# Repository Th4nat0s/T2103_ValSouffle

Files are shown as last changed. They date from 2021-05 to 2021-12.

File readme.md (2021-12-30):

Blow Gun controller for CNC
===========================

Print it on your CNC !

Push code to arduino
--------------------------------

### Arduino
Usb connection 
arduino framework 

Tips
----
`./serial` launch serial console through buspirate  
`pio run -t idedata` update libs, perpare env  
`pio run -t fuses` set the fuses  
`pio run -t upload -e release|debug` upload  a specific release version without serial debug  
`pio platform update --dry-run` check for updates

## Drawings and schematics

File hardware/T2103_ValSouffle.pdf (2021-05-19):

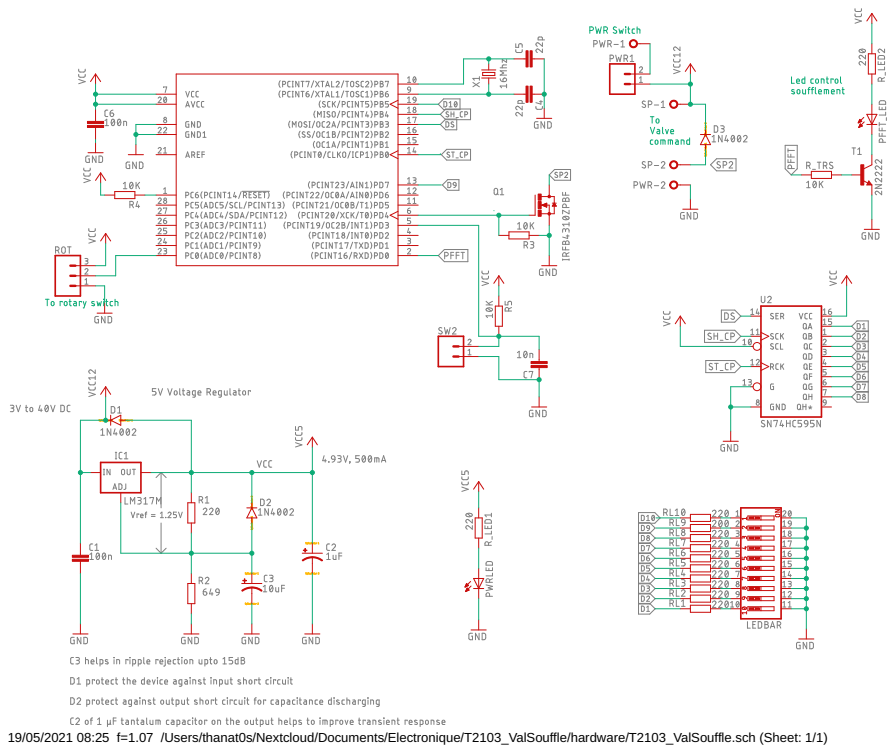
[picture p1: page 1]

19/05/2021 08:25 f=1.07 /Users/thanat0s/Nextcloud/Documents/Electronique/T2103_ValSouffle/hardware/T2103_ValSouffle.sch (Sheet: 1/1)

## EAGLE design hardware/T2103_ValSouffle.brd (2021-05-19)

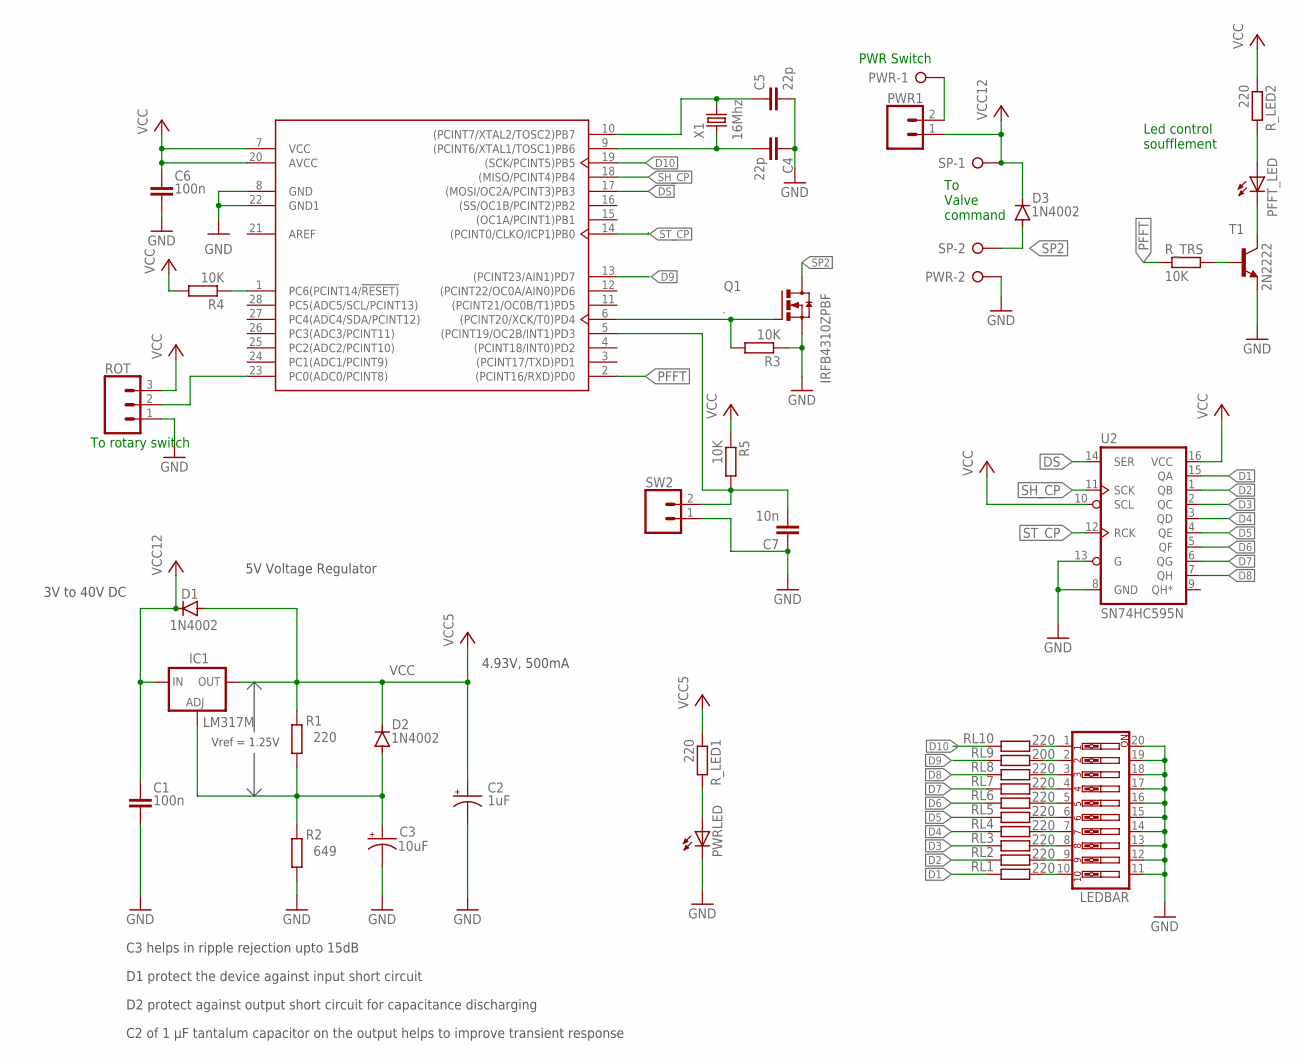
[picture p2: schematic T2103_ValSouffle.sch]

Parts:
C1, C6: 100n; C050-030X075
C2: 1uF; E1,8-4
C3: 10uF; E1,8-4
C4, C5: 22p; C025-025X050
C7: 10n; C025-025X050
D1, D2, D3: 1N4002; DO41-10
IC1: LM317MB; TO220L1; PARTNUMBER LM317M
LEDBAR: SW_DIP-10; EDG-10
PFFT_LED: LED5MM
PWR: W237-02P; W237-132
PWR1: CONN_02; 1X02
PWRLED: LED5MM
Q1: IRFB4310ZPBF; TO-220
R1: 220; 0207/10
R2: 649; 0207/10
R3, R4, R5: 10K; 0207/10
RL1, RL2, RL3, RL4, RL5, RL6, RL7, RL8, RL10: 220; 0207/10
RL9: 200; 0207/10
ROT: CONN_03; 1X03
R_LED1, R_LED2: 220; 0207/10
R_TRS: 10K; 0207/10
SP: W237-02P; W237-132
SW2: CONN_02; 1X02
T1: 2N2222; TO92-EBC-OVAL
U1: ATMEGA328P-PU; DIP-28
U2: SN74HC595N; DIP16
X1: 16Mhz; XTAL_HC49

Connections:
D1: RL1.2, U2.15 (QA)
D2: RL2.2, U2.1 (QB)
D3: RL3.2, U2.2 (QC)
D4: RL4.2, U2.3 (QD)
D5: RL5.2, U2.4 (QE)
D6: RL6.2, U2.5 (QF)
D7: RL7.2, U2.6 (QG)
D8: RL8.2, U2.7 (QH)
D9: RL9.2, U1.13 ((PCINT23/AIN1)PD7)
D10: RL10.2, U1.19 ((SCK/PCINT5)PB5)
DS: U1.17 ((MOSI/OC2A/PCINT3)PB3), U2.14 (SER)
GND: C1.2, C2.-, C3.-, C4.1, C5.2, C6.2, C7.1, LEDBAR.11, LEDBAR.12, LEDBAR.13, LEDBAR.14, LEDBAR.15, LEDBAR.16, LEDBAR.17, LEDBAR.18, LEDBAR.19, LEDBAR.20, PWR.2, PWRLED.K (C), Q1.S, R2.1, R3.1, ROT.1, SW2.1, T1.E, U1.8 (GND), U1.22 (GND1), U2.8 (GND), U2.13 (G)
unnamed: C3.+, D2.A, IC1.1 (ADJ), R1.1, R2.2
unnamed: C4.2, U1.9 ((PCINT6/XTAL1/TOSC1)PB6), X1.1
unnamed: C5.1, U1.10 ((PCINT7/XTAL2/TOSC2)PB7), X1.2
unnamed: Q1.G, R3.2, U1.6 ((PCINT20/XCK/T0)PD4)
unnamed: R4.1, U1.1 (PC6(PCINT14/!RESET))
unnamed: LEDBAR.1, RL10.1
unnamed: LEDBAR.2, RL9.1
unnamed: LEDBAR.3, RL8.1
unnamed: LEDBAR.4, RL7.1
unnamed: LEDBAR.5, RL6.1
unnamed: LEDBAR.6, RL5.1
unnamed: LEDBAR.7, RL4.1
unnamed: LEDBAR.8, RL3.1
unnamed: LEDBAR.9, RL2.1
unnamed: LEDBAR.10, RL1.1
unnamed: ROT.2, U1.23 (PC0(ADC0/PCINT8))
unnamed: PFFT_LED.A, R_LED2.2
unnamed: PFFT_LED.K (C), T1.C
unnamed: PWRLED.A, R_LED1.2
unnamed: R_TRS.2, T1.B
unnamed: C7.2, R5.2, SW2.2, U1.5 ((PCINT19/OC2B/INT1)PD3)
PFFT: R_TRS.1, U1.2 ((PCINT16/RXD)PD0)
SH_CP: U1.18 ((MISO/PCINT4)PB4), U2.11 (SCK)
SP2: D3.A, Q1.D, SP.2
ST_CP: U1.14 ((PCINT0/CLKO/ICP1)PB0), U2.12 (RCK)
VCC: C2.+, C6.1, D1.A, D2.C, IC1.2 (OUT), R1.2, R4.2, R5.1, ROT.3, R_LED1.1, R_LED2.1, U1.7 (VCC), U1.20 (AVCC), U2.10 (SCL), U2.16 (VCC)
VCC12: C1.1, D1.C, D3.C, IC1.3 (IN), PWR1.1, SP.1
VCCSHUT: PWR.1, PWR1.2

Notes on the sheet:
5V Voltage Regulator
C3 helps in ripple rejection upto 15dB
D1 protect the device against input short circuit
D2 protect against output short circuit for capacitance discharging
C2 of 1 µF tantalum capacitor on the output helps to improve transient response
4.93V, 500mA
3V to 40V DC
Vref = 1.25V
Led control soufflement
PWR Switch
To Valve command
To rotary switch

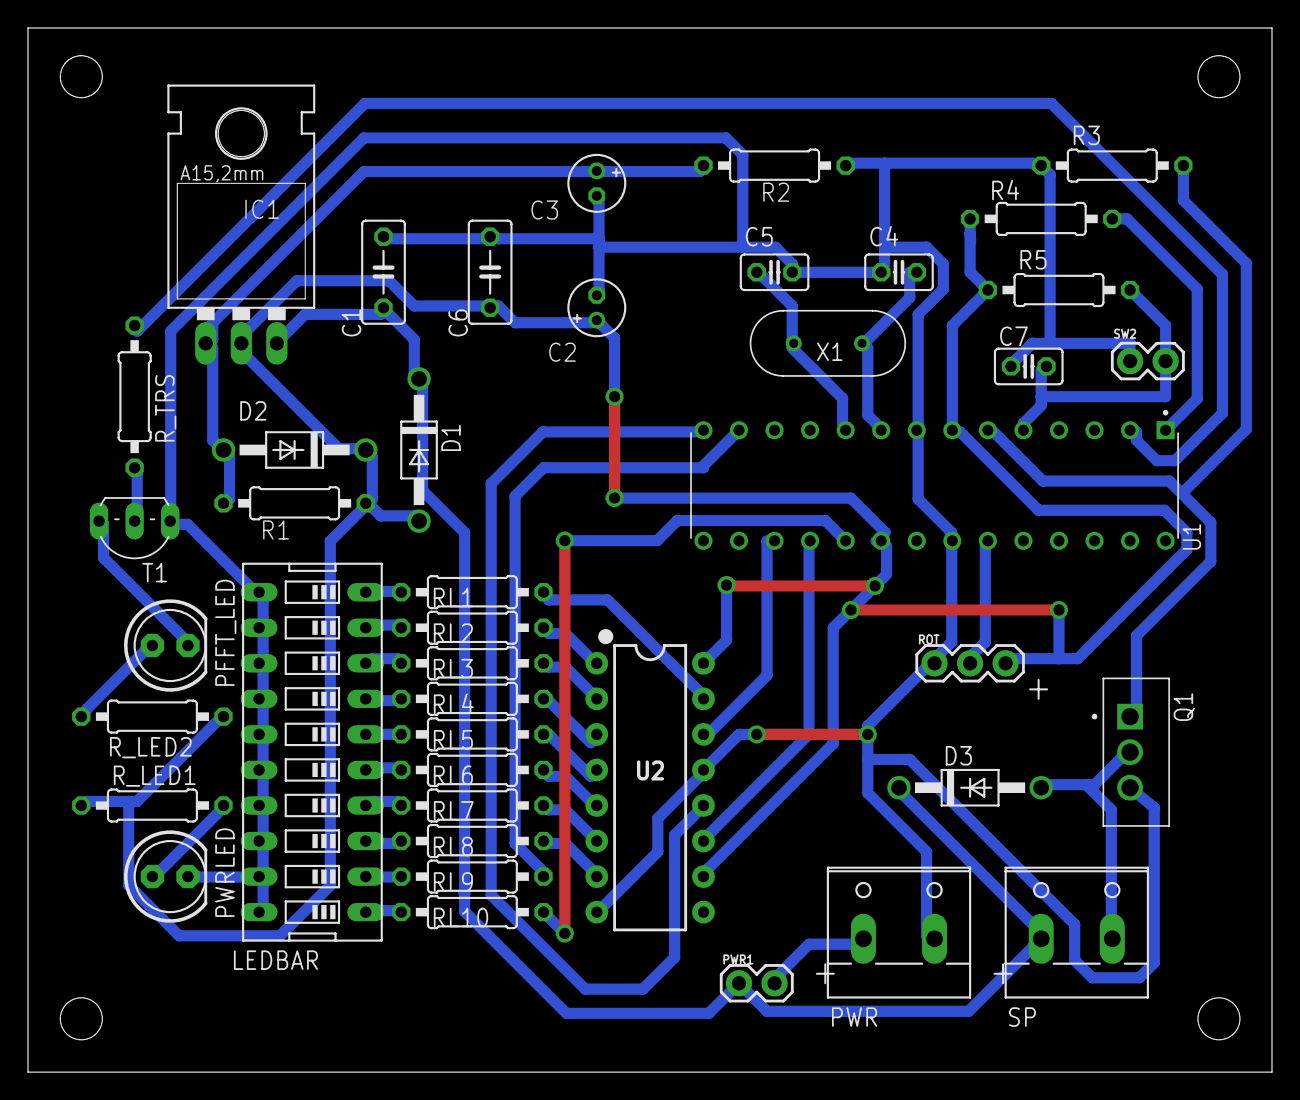
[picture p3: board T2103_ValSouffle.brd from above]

Board: 2 copper layers, 88.9 x 74.6 mm, 42 parts (0 on the bottom side), 40 nets.

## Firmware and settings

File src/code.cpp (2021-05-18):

/*
____   ____      .__      _________              _____  _____.__
\   \ /   /____  |  |    /   _____/ ____  __ ___/ ____\/ ____\  |   ____
 \   Y   /\__  \ |  |    \_____  \ /  _ \|  |  \   __\\   __\|  | _/ __ \
  \     /  / __ \|  |__  /        (  <_> )  |  /|  |   |  |  |  |_\  ___/
   \___/  (____  /____/ /_______  /\____/|____/ |__|   |__|  |____/\___  >
               \/               \/                                     \/
                    Copyleft Thanat0s Since march 2021

Code for Atmega328p microcontroller.
https://github.com/Th4nat0s/T2103_ValSouffle

Greets fly to SMHOSY, Entercar68

                  ATMEL Atmega328p / (ARDUINO Uno)

                             +-\/-+
            RST        PC6  1|    |28  PC5  (A5)    SCL
            Rx  (D0 )  PD0  2|    |27  PC4  (A4)    SDA
            Tx  (D1 )  PD1  3|    |26  PC3  (A3)
                (D2 )  PD2  4|    |25  PC2  (A2)
    PWM T2      (D3~)  PD3  5|    |24  PC1  (A1)
                (D4 )  PD4  6|    |23  PC0  (A0)
                       VCC  7|    |22  GND
                       GND  8|    |21  AREF
         Xtal1  (   )  PB6  9|    |20  AVCC
         Xtal2  (   )  PB7 10|    |19  PB5  (D13 )  SCK
        PWM T0  (D5~)  PD5 11|    |18  PB4  (D12 )  MISO
        PWM T0  (D6~)  PD6 12|    |17  PB3  (D11~)  MOSI PWM T2
                (D7 )  PD7 13|    |16  PB2  (D10~)       PWM T1
                (D8 )  PB0 14|    |15  PB1  (D 9~)       PWM T1
                             +----+

                 20 mA per pin / 200 mA overall

*/

#include <Arduino.h>

/*
____   ____            .__      ___.   .__
\   \ /   /____ _______|__|____ \_ |__ |  |   ____   ______
 \   Y   /\__  \\_  __ \  \__  \ | __ \|  | _/ __ \ /  ___/
  \     /  / __ \|  | \/  |/ __ \| \_\ \  |_\  ___/ \___ \
   \___/  (____  /__|  |__(____  /___  /____/\___  >____  >
               \/              \/    \/          \/     \/
*/

// Connections to the  74HC595 ( 8 Bit led driver )
const int latchPin = 8;  // PB0 connected to ST_CP
const int clockPin = 12;   // PB4 connected to SH_CP
const int dataPin = 11;   // PB3 connected to DS

// Connections to the leds
const int ledh1 = 7;   //  PD7 connected to Bit 9 - Led
const int ledh2 = 13;   //  PB5 connected to Bit 10 - Led
const int pfft = 0;  // PD0 connection to pffft led.

// Input pins
const int potPin = 0;     // PC2 selector, input pin for the potentiometer
const int ButtonPin = 3;  // PD3, manual blower button

// Output pins
const int t_pfft = 4;  // PD4 connection to the blower driver.

// Variables will change:
int but_pushed;
int buttonPushCounter = 0;   // counter for the number of button presses
int buttonState = 0;         // current state of the button
int lastButtonState = 0;     // previous state of the button


unsigned int val = 0;       // variable to store the value coming from the sensor
//float n = 0;
int bit;
bool bith1;
bool bith2;

unsigned long action = millis();

int pwr_slct;  // <- Int = 16 Bytes. 

// Valeurs Min/Max Potar (For 10K varistor)
unsigned int max_pot = 700; //1024 ;// 877;
unsigned int min_pot = 26;
unsigned int borne_max;
unsigned int borne_min;


// Configuration for the delays of the blower...
// Timers are in milliseconds.. 1sec = 1000ms
// 0 is special it means OFF !
//                Position  0    1       2      3      4      5     6     7     8    9   10
unsigned int pfftwait[] =  {0, 60000, 30000, 25000, 20000, 10000, 5000, 2000, 1000, 500 ,250};
// Time to Pfft in millseconds..
unsigned int pffttime[] = {0,  3000,  3000,  3000,  3000,  1000,  1000, 500,  500,  500, 250};


int pffstatus = 0; // status of the blower 0 Sleeping... 1 pffting...
unsigned int cpfftwait; // current wait selected time
unsigned int cpffttime; //


/*
.___       .__  __
|   | ____ |__|/  |_
|   |/    \|  \   __\
|   |   |  \  ||  |
|___|___|  /__||__|
         \/
*/

void setup() {
  //Start Serial for debuging purposes
  Serial.begin(9600);
  // Set various pins to in or output
  pinMode(latchPin, OUTPUT);
  pinMode(ledh1, OUTPUT); // Led 9
  pinMode(ledh2, OUTPUT);  // Led 10
  pinMode(pfft, OUTPUT);   // Led showing blow
  pinMode(t_pfft, OUTPUT);  // Transistor output for Blowing
  pinMode(ButtonPin, INPUT);  // Input button
  digitalWrite(pfft, 1);  // Active le pfft.
  delay(1000);
  digitalWrite(pfft, 0);  // Active le pfft.
  // Calcul des min / max potar.
  borne_max = (((max_pot - min_pot) / 11) * 10) + min_pot;
  borne_min = ((max_pot - min_pot) / 11) + min_pot;
}

void readbutton() {
  // read the pushbutton input pin update the status "but_pushed":
  buttonState = digitalRead(ButtonPin);
  // compare the buttonState to its previous state
  if (buttonState != lastButtonState) {
    // if the state has changed, increment the counter
    if (buttonState == HIGH) {
      // if the current state is HIGH then the button went from off to on:
     buttonPushCounter++;
     but_pushed = true;
    } else {
      // if the current state is LOW then the button went from on to off:
      but_pushed = false;
    }
  }
  // save the current state as the last state, for next time through the loop
  lastButtonState = buttonState;
}

void shiftOut(int myDataPin, int myClockPin, byte myDataOut) {
  // This shifts 8 bits out MSB first,
  //on the rising edge of the clock,
  //clock idles low
  //internal function setup
  int i = 0;
  int pinState;
  pinMode(myClockPin, OUTPUT);
  pinMode(myDataPin, OUTPUT);
  //clear everything out just in case to
  //prepare shift register for bit shifting
  digitalWrite(myDataPin, 0);
  digitalWrite(myClockPin, 0);
  //for each bit in the byte myDataOut&#xFFFD;
  //NOTICE THAT WE ARE COUNTING DOWN in our for loop
  //This means that %00000001 or "1" will go through such
  //that it will be pin Q0 that lights.
  for (i = 7; i >= 0; i--)  {
    digitalWrite(myClockPin, 0);
    //if the value passed to myDataOut and a bitmask result
    // true then... so if we are at i=6 and our value is
    // %11010100 it would the code compares it to %01000000
    // and proceeds to set pinState to 1.
    if ( myDataOut & (1 << i) ) {
      pinState = 1;
    }
    else {
      pinState = 0;
    }
    //Sets the pin to HIGH or LOW depending on pinState
    digitalWrite(myDataPin, pinState);
    //register shifts bits on upstroke of clock pin
    digitalWrite(myClockPin, 1);
    //zero the data pin after shift to prevent bleed through
    digitalWrite(myDataPin, 0);
  }
  //stop shifting
  digitalWrite(myClockPin, 0);
}

/*
   _____         .__
  /     \ _____  |__| ____
 /  \ /  \\__  \ |  |/    \
/    Y    \/ __ \|  |   |  \
\____|__  (____  /__|___|  /
        \/     \/        \/
*/

void loop() {
  val = analogRead(potPin);    // read the value from the rotary
  readbutton();  // read the value from the button.

  // Convertis la valeur du potar en 11 Positions possibles.
  pwr_slct = (val - min_pot ) / ((max_pot - min_pot) / 11) ;

  Serial.println();
  Serial.print ( "Pwr Select: ");
  Serial.print (pwr_slct);


  // If Min or Max
  if (val < borne_min)  pwr_slct = 0 ;
  if (val >= borne_max)  pwr_slct = 10 ;

  // Convert power selected in LED bits.
  bit = 0; 
  for (int i = pwr_slct-1; i >= 0; i--)  {  // Down count !
    bit = bit | (1 << i);
  }

  // Select value for bit 9 & 10..
  bith1 = (bit >> 8) & 0x1;
  bith2 = (bit >> 9) & 0x1;
  bit = bit & 0xff;  // Push bit back to 8 Bits before printing.

  // Mets à jour l'affichage des leds.
  digitalWrite(latchPin, 0);
  shiftOut(dataPin, clockPin, bit);
  digitalWrite(latchPin, 1);
  digitalWrite(ledh1, bith1);  // Led 9 and 10
  digitalWrite(ledh2, bith2);

  // Determine time of sleeping and pffting based on power selected.
  cpffttime = pffttime[pwr_slct];
  cpfftwait = pfftwait[pwr_slct];

  Serial.print ( "val: ");
  Serial.print (cpffttime);
  Serial.print(" button:  ");
  Serial.print(but_pushed);


  unsigned long t = millis();  // Get time. 
  // If power is to 0 ( stop )... do nothing.
  if (pwr_slct == 0 ) {
      digitalWrite(pfft, 0);  // deActive le pfft.
      digitalWrite(t_pfft, 0);  // deActive le pfft.
      pffstatus = 0;
  } else {
    // if not to 0... 
    // Ovverride avec le bouton blow on off
    if (but_pushed == 0) {
      digitalWrite(pfft, 1);  // Active le pfft.
      digitalWrite(t_pfft, 1);  // Active le pfft.
      pffstatus = 1;
      action = t + action ; // Invalidate timer.
      } else {

      // if not position 0 and button released then... look a time
      // Wait and Loop.
      // If power select is <> of 0...
      if (pffstatus == 1 and pwr_slct != 0 ) {
        // Wait le temps qu'il faut.
        if ( ( t - action ) > cpffttime ) {
          action = t;  // Schedule next action
          Serial.print("Wait");  
          digitalWrite(pfft, 0);  // Stop le pfft.
          digitalWrite(t_pfft, 0);  // Stop le pfft.
          pffstatus = 0;    // Set le status on pffft pas.
        }
      } else if (pwr_slct != 0) {
        // Souffle le temps qu'il faut.
        if ( ( t - action ) > cpfftwait  ) {
          action = t;
          Serial.print("Souffle");  
          digitalWrite(pfft, 1);  // Active le pfft.
          digitalWrite(t_pfft, 1);  // Active le pfft.
          pffstatus = 1;    // set le status on pfuiiiit 
        }
      }
    }
  }
}

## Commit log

2021-03-24 1st push arduinoide code
2021-04-03 finalize routing
    [T2103_ValSouffle.brd, T2103_ValSouffle.sch]
2021-04-05 Add manual switch
    [T2103_ValSouffle.brd, T2103_ValSouffle.sch]
2021-04-07 update slide led code
2021-04-07 finalise motor control
2021-05-18 test on device printed
2021-05-18 Hardware update
    [T2103_ValSouffle.brd, T2103_ValSouffle.sch]
2021-05-19 update graph
    [T2103_ValSouffle.brd, T2103_ValSouffle.sch]

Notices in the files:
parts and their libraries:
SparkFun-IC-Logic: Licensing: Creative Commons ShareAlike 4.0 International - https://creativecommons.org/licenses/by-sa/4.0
